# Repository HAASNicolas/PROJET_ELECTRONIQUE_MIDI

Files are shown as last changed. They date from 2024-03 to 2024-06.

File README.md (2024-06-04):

# PROJET_ELECTRONIQUE_MIDI
## Participants
* Lina Bachir
* Nicolas Haas
* Tanoh Koffi

## Code C
```C
int main (void)
{
  printf(C);
}
```

## Commandes github
Sous window: Dans le répertoire faire clique droit 'ouvrir un git bach', puis aller dans le bon dossier (si c'est pas déjà le cas):

Sous linux: Ouvrir un terminal, puis aller dans le bon dossier. Par exemple :
```
cd Documents/git_1A/PROJET_ELECTRONIQUE_MIDI/
```

Pour créer un nouveau répertoire git:
```
git config --global user.name "Pseudo git ou Nom Prénom"
git config --global user.email "Votre e-mail"
```
Testez
```
git clone adresse_du_git
```
Si git clone marche: Vous avez fini !
Sinon si git clone ne marche pas:
```
ssh-keygen
```
Faites Entrer plusieurs fois, puis copier l'adresse /c/....pub (example: /c/Users/user_name/.ssh/id_ed25519.pub)
```
cat adresse_pub_copié_ci_dessus
```
Copier ssh key, puis Ajouter ssh key sur github.com -> setting -> sshkey
```
git clone adresse_du_git
```

Pour récupérer les modifications distantes :
```
git pull
```

Pour pousser des modifications locales
```
git add .
git commit -m "Message à remplacer"
git push
```
# Rapport projet 
## Introduction

Notre projet consiste en la création d’un contrôleur MIDI, un dispositif électronique conçu pour interagir avec divers instruments et logiciels musicaux. Le contrôleur comporte une variété de boutons, de potentiomètres et de curseurs, offrant un contrôle précis et intuitif de nombreux aspects de la production musicale, tels que le volume, les effets, et la modulation.

La conception du contrôleur inclut l’intégration de plusieurs capteurs pour détecter les actions de l’utilisateur, qui sont ensuite traduites en signaux MIDI. Ces signaux sont transmis à un ordinateur ou un autre appareil musical via une interface MIDI, permettant un contrôle en temps réel de la musique.

Le développement de ce contrôleur MIDI inclut la mise en œuvre d’une carte électronique centrale, qui gère les signaux provenant des différents capteurs, ainsi qu’une interface de sortie pour la communication avec les appareils externes.

## objectif

L'objectif de notre projet est de concevoir un contrôleur MIDI fonctionnel et intuitif, permettant aux musiciens et aux producteurs de gérer et de manipuler leurs compositions musicales de manière fluide. 
Nous cherchons à créer un dispositif qui permette un contrôle précis et efficace des éléments clés de la production musicale, tels que le volume, les effets, et la modulation.

* Implémentation du MIDI classique

  Nous voulons une compatibilité universelle avec beaucoup d'instruments et de logiciels musicaux en adoptant le protocole MIDI standard. Notre contrôleur sera conçu pour envoyer et recevoir des messages MIDI de façon fiable, facilitant ainsi son intégration dans diverses configurations musicales.

* Support du MIDI USB via USB-C

  Notre objectif est d'incorporer une interface MIDI moderne utilisant un port USB-C, permettant une connexion simple et efficace avec des ordinateurs et autres appareils prenant en charge l'USB. Cela englobera la transmission de données MIDI ainsi que l'alimentation du contrôleur.

* Autonomie sur batterie rechargeable

  Nous planifions de développer un contrôleur fonctionnant sur une batterie rechargeable pour maximiser la portabilité et la flexibilité d'utilisation. La batterie sera rechargeable via USB-C, offrant ainsi aux utilisateurs la possibilité de jouer sans être dépendant d'une source d'alimentation fixe.

* Inspirations et benchmarking

  Nous nous baserons sur des modèles de référence tels que l'Intech Studio PBF4, le Faderfox MX12 pour l'ergonomie et l'AKAI MIDIMIX pour sa disposition efficace. Ces produits nous serviront de guide dans le développement de notre contrôleur.

* Cahier des charges:
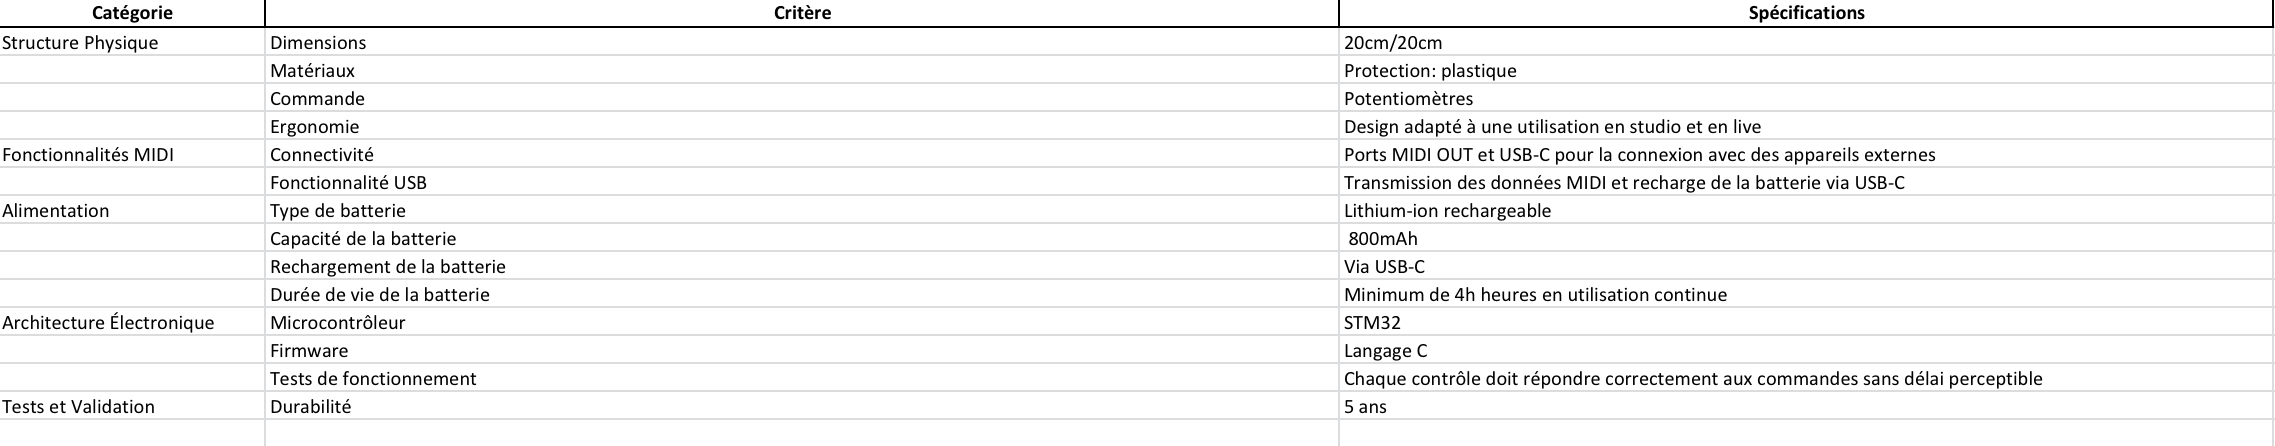
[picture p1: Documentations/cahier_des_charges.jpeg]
cahier des charges


* Planning des séances
planning

* Schéma global du projet

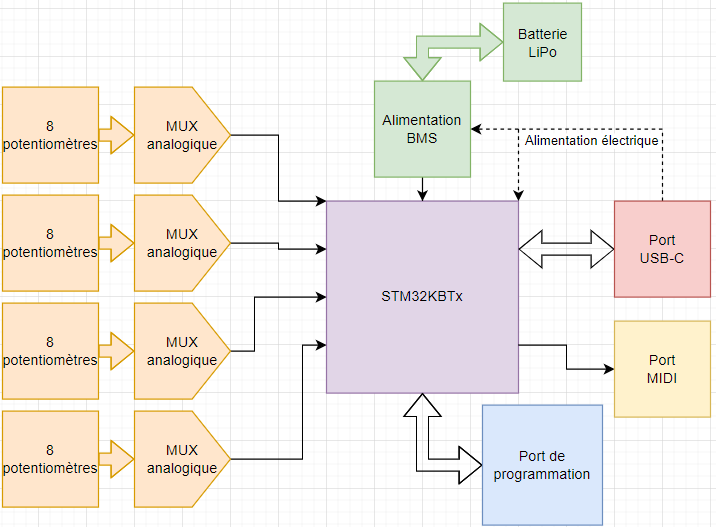
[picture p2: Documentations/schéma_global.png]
Schéma global du projet
  

## PCB 

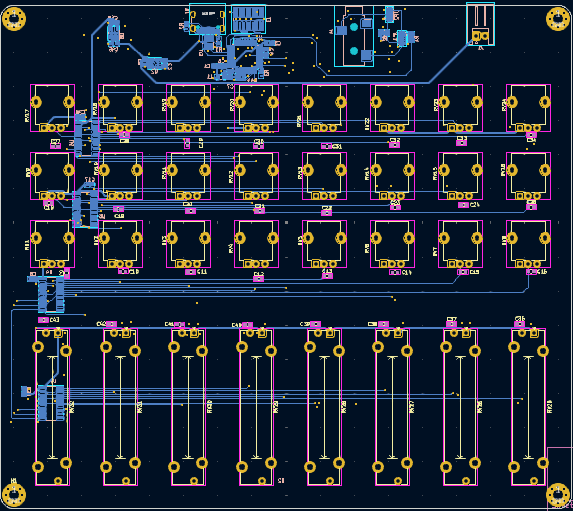
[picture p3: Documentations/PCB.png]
PCB


Dans cette partie de ce rapport, nous donnerons un aperçu complet de l'architecture et des composants du PCB de ce contrôleur MIDI.
On cherchera donc ici à comprendre le rôle des composants sur ce PCB et leur disposition.
Concernant le Microcontrôleur, ici le STM 32 KBTX, il est le centre du contrôleur MIDI. Son but ici est de gérer les entrées venues des boutons et potentiomètres, de traiter ces informations et d’envoyer les messages MIDI appropriés via les interfaces MIDI ou USB.

Quant aux Régulateurs de tension, ils assurent une tension stable pour alimenter les différents composants du circuit, par exemple, fournir 5V pour le microcontrôleur et 3.3V pour certains capteurs ou circuits.

On a aussi utilisé des Condensateurs pour filtrer les signaux, déparasiter les lignes d'alimentation et stabiliser les tensions. Ils sont essentiels pour réduire le bruit électronique et maintenir la stabilité des signaux. Ils sont dispersés autour du microcontrôleur et près des régulateurs de tension, souvent à proximité des broches d'alimentation pour optimiser leur efficacité. De plus, avec les Résistances, on parviendra à Limiter le courant, ajuster les niveaux de tension et effectuer des fonctions pull-up/pull-down sur les lignes de signal, elles sont quant à elles Connectées en série avec les boutons et situées près du microcontrôleur pour les pull-ups/pull-downs.

Le Connecteur MIDI utilisé ici va servir d’interface afin de connecter le contrôleur MIDI à d'autres dispositifs MIDI. Ce connecteur permet donc la communication des données MIDI. Un autre type de connecteur utilisé est le Connecteur USB qui va Permettre la connexion du contrôleur à un ordinateur pour la transmission de données MIDI et l'alimentation.

Les Traces, Les lignes rouges et bleues sur le schéma représentent les connexions électriques entre les composants. Les rouges sont sur la couche supérieure du PCB, et les bleues sur la couche inférieure. Elles sont connectées entre les différentes couches du PCB à l’aide des Vias, qui assurent ainsi une interconnexion entre les couches du PCB. Les potentiomètres, eux, capturent les entrées de l'utilisateur. Chaque potentiomètre envoie en effet un signal spécifique au microcontrôleur.

En outre, Le microcontrôleur central gère les entrées venues des boutons et les interfaces MIDI/USB. Les régulateurs de tension, condensateurs et résistances assurent la stabilité du circuit et les connecteurs MIDI et USB permettent la communication avec d'autres dispositifs MIDI et des ordinateurs.
En résumé, lorsqu'on modifie la position d’un potentiomètre du contrôleur MIDI, le microcontrôleur détecte ce changement et identifie le potentiomètre en question. Il génère ensuite un message MIDI avec les informations appropriées (comme la note et la vélocité). Ce message est transmis soit via le connecteur MIDI DIN à d'autres appareils MIDI, soit via USB à un ordinateur.

## Résultats
Nous avons réussi à faire fonctionner la carte, et a lui faire envoyer, via l'USART, des trames MIDI correspondants aux valeurs des potentiomètres.

Voici les valeurs que renvoient un des potentiomètres linéaire et un des potentiomètres rond. C'est valeurs doivent être comprise entre 0 et 127, car en MIDI on la code sur 7 bits.
Sel est le numéro transmis aux 4 MUX analogiques.
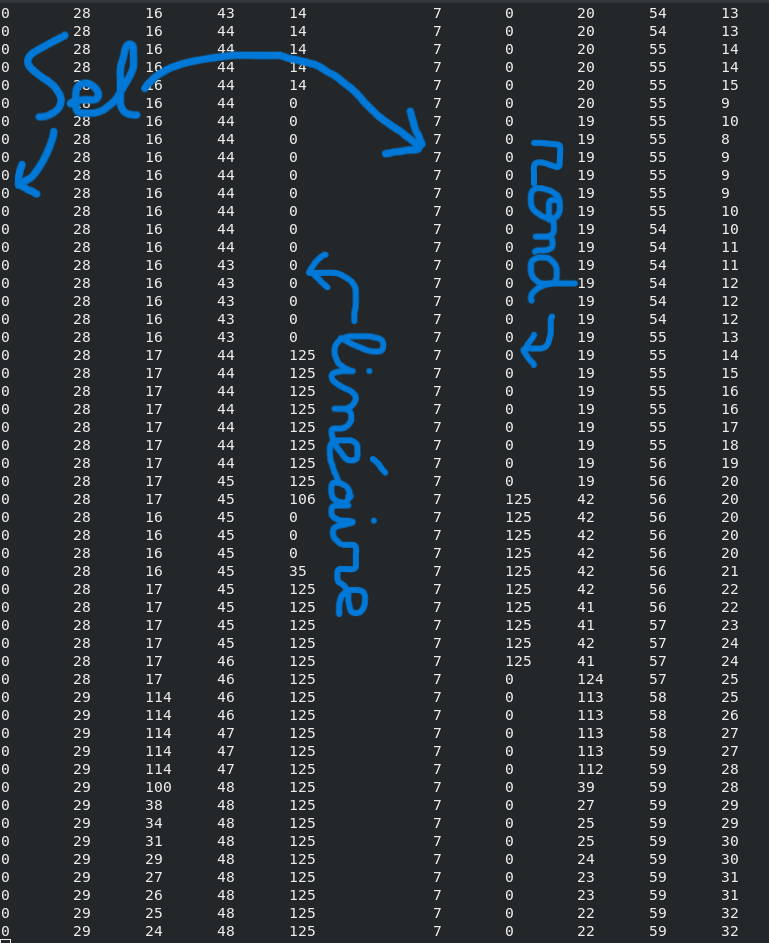
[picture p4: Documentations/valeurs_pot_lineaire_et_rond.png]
Valeurs des potentiomètres


La carte regarde en boucle la valeur des potentiomètres. Si la valeur change, alors une trame MIDI est envoyée.

Comme l'ADC fait 4 conversions à la fois, nous pouvons voir 4 trames MIDI qui ce suivent:
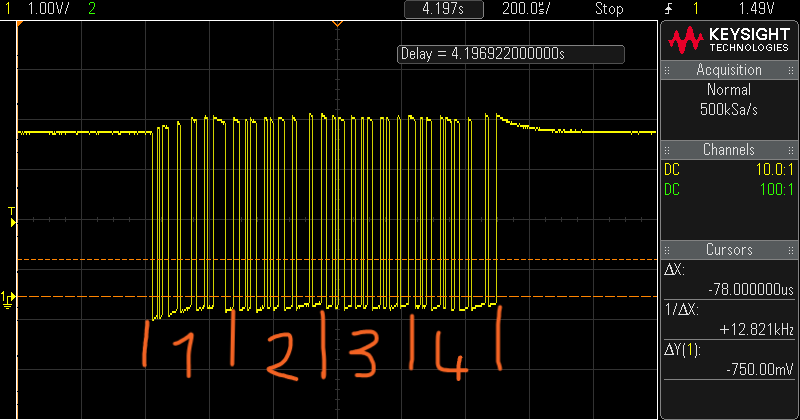
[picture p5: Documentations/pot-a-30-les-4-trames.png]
4 trames MIDI


Chaque trame comporte 3 octets, ayant chacun leur bit de start à 0.
* Le 1er octet et l'identifiant ici 0x1A
* Le 2e est le numéro du potentiomètre ici 24
* Le 3e et dernier est la valeur du potentiomètre (ici 30) codée sur 7 bits (donc le MSB qui se situe à droite est toujours à 0)

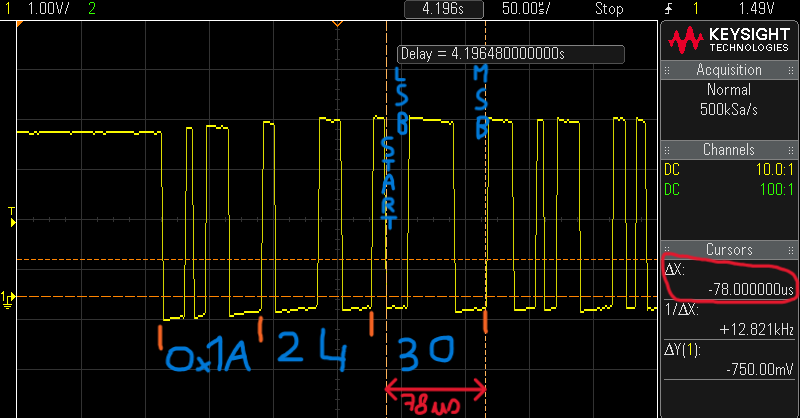
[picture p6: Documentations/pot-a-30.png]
Trame MIDI d'un potentiomètre de valeur 30


On remarque que les curseurs sont espacés de 9 bits et d'une durée de 78us. Ce qui est en accord avec notre programme que nous avons configuré pour émettre à une vitesse de 115200 bauds.

## Code

Voici le diagramme de notre code:

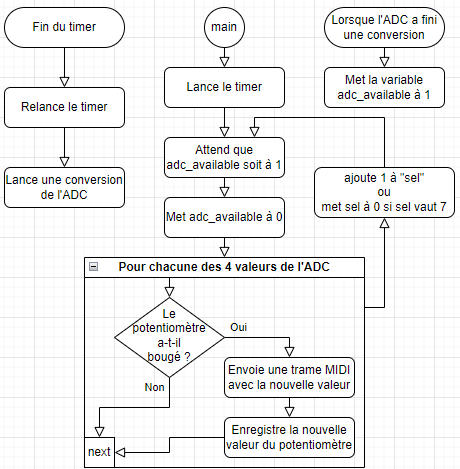
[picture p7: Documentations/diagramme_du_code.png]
Diagramme du code


## Les difficultés rencontrées

* Lors de schéma afain d'avoir les bonnes valeurs des résistances et condensateurs.
* Le routage nous a aussi appris qu'il faut mettre des composants de protections, ainsi que le BMS pour la recharge de la batterie.
* Dans le routage, qui nous ont permis d'apprendre les bonnes pratiques.
* L'USART du STM32 ne voulait pas fonctionner en Half-Duplex, on a donc dû le mettre en Asynchronous. Nous avons donc la broche TX qui ne sert à rien.
* Pour le soudage de composants CMS, car il faut être précis.

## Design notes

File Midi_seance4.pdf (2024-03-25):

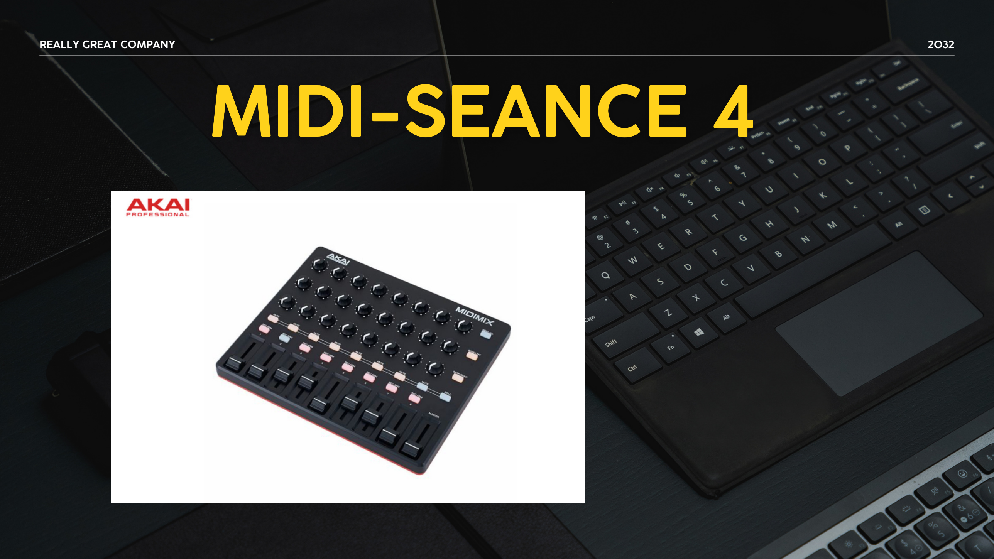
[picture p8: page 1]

REALLY GREAT COMPANY | 2032

3

1.

# 2. DEBUT ROUTAGE

# FIN SHEMA KICAD

# SCHEMA KICAD

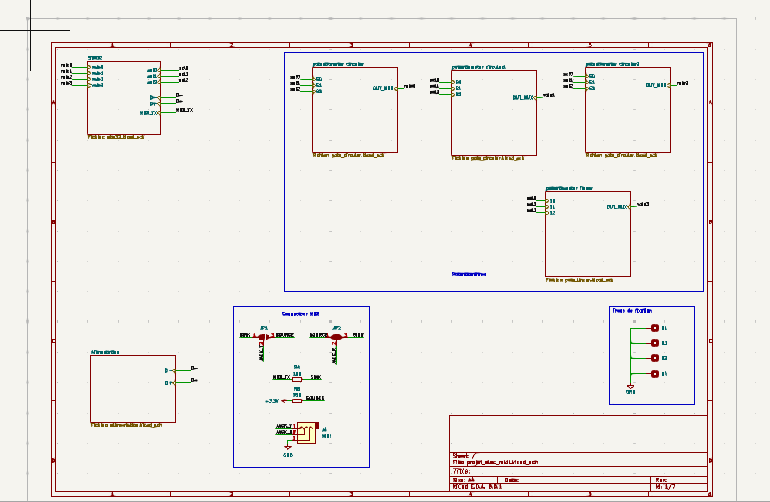
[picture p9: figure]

# KICAD

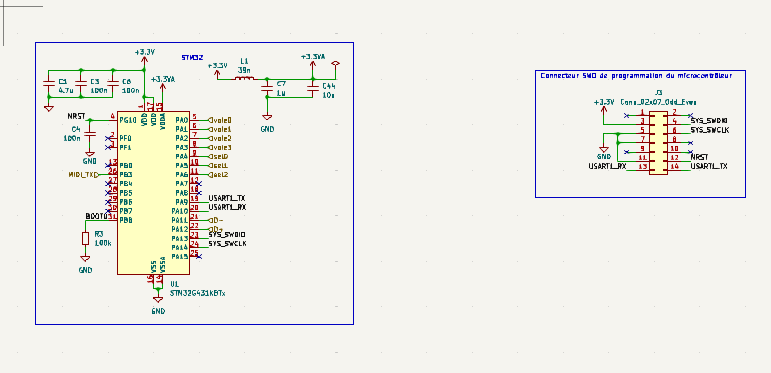
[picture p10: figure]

# KICAD

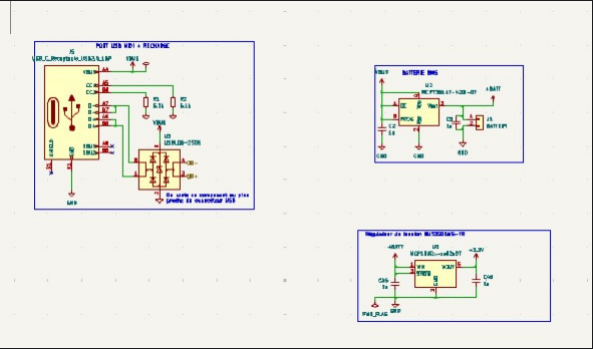
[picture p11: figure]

# KICAD

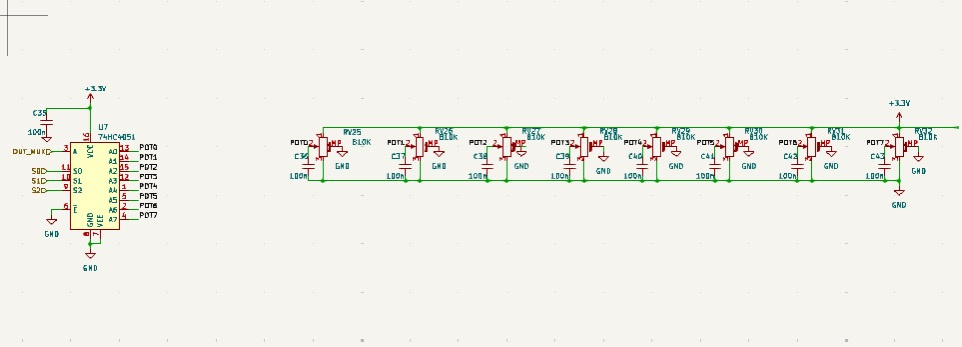
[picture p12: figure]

# ROUTAGE

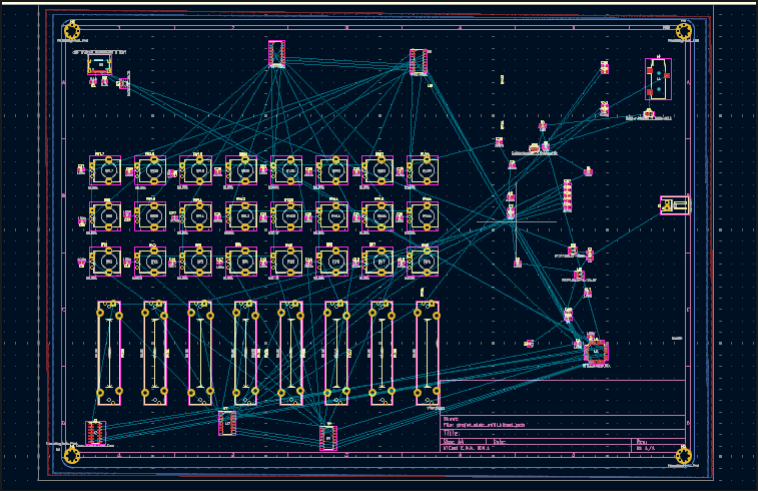
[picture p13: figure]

# MERCI !

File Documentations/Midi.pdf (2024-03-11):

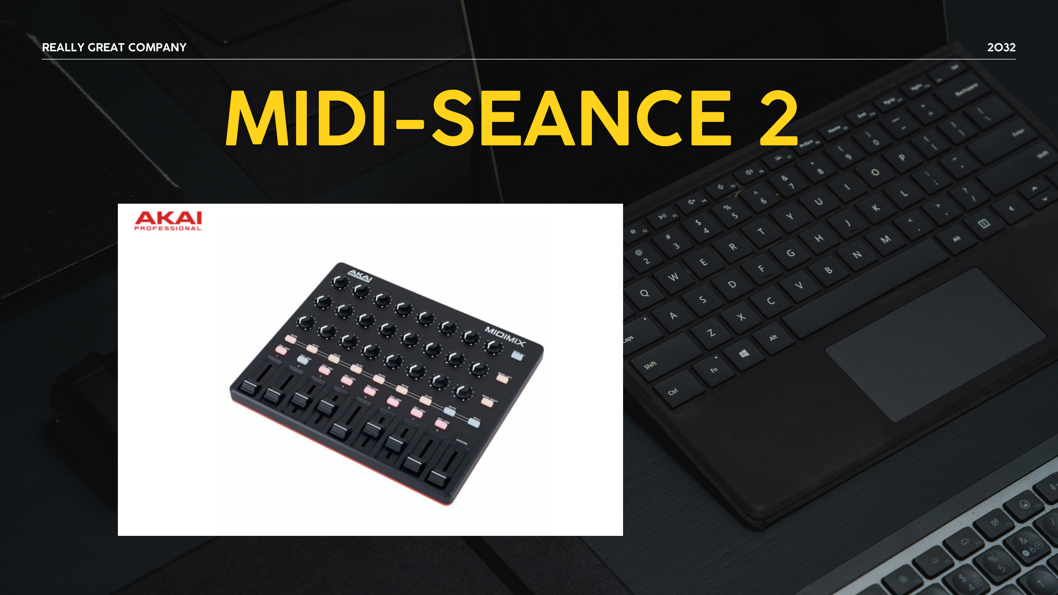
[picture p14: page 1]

REALLY GREAT COMPANY | 2032

3

1.

# 2. DEBUT KICAD

# CHOIX DES COMPOSANTS

1.

# 2. DEBUT KICAD

# CHOIX DES COMPOSANTS

# CHOIX DES COMPOSANTS

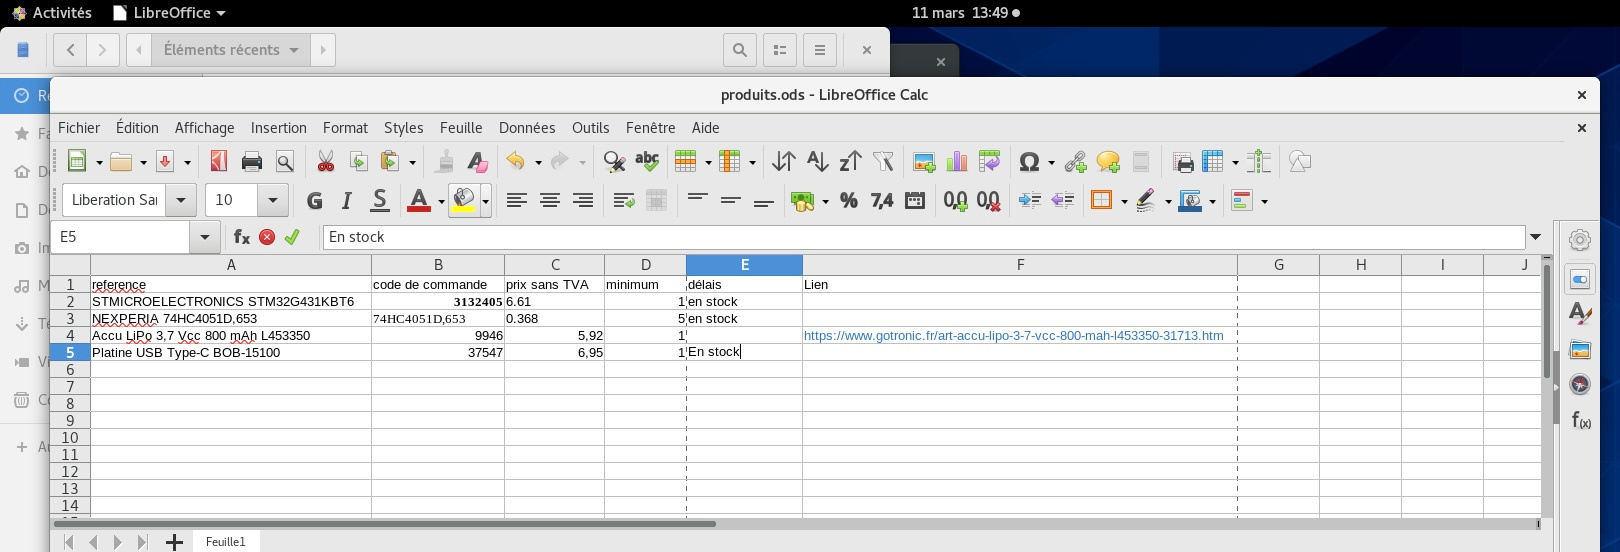
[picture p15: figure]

# DEBUT KICAD

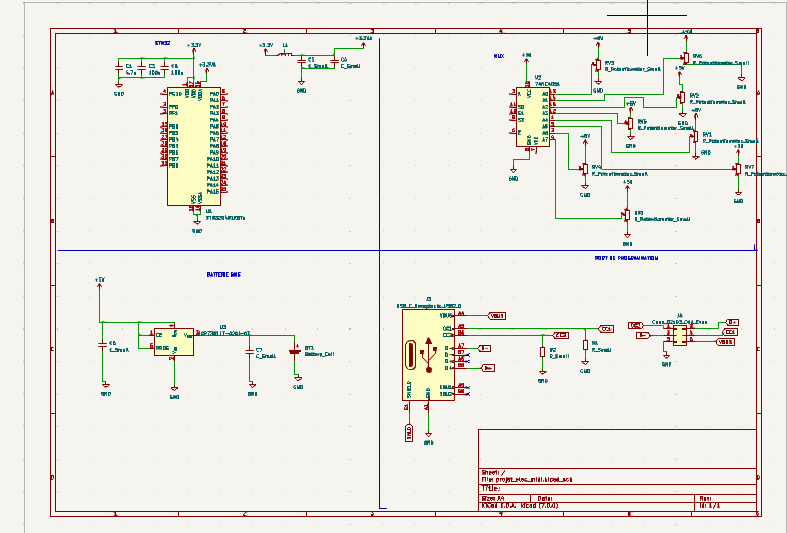
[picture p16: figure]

# MERCI !

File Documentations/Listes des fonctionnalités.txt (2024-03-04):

-recevoir en entrée plusieurs sons et émettre en sortie un seul son
- Contrôler le volume du son, la panoramique, le gain 
-

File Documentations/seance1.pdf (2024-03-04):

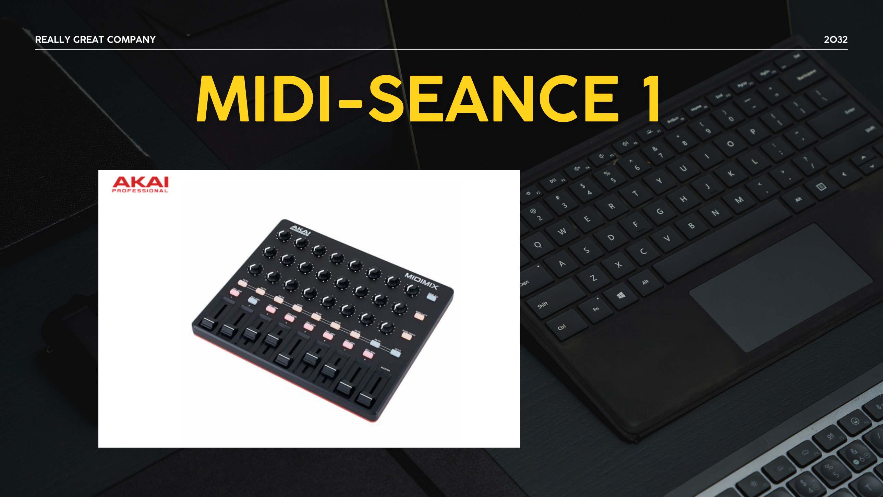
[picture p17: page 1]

REALLY GREAT COMPANY | 2032

REALLY GREAT COMPANY | 2032

3

1.

# 2.SCHEMA ARCHITECTURAL

# LISTE DES COMPOSANTS

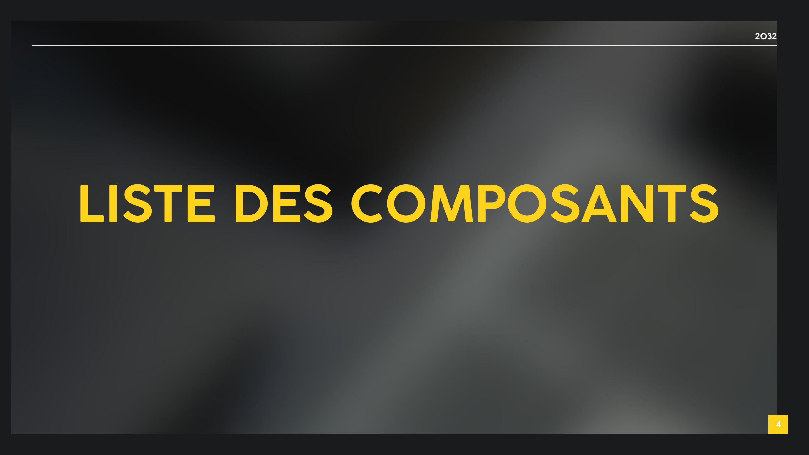
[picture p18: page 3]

4

2032

# LISTE DES COMPOSANTS

5

# 32 POTENTIOMETRE MULTIPLEXEUR ANALOGIQUE BATTERIE PORT DE PROGRAMMATION

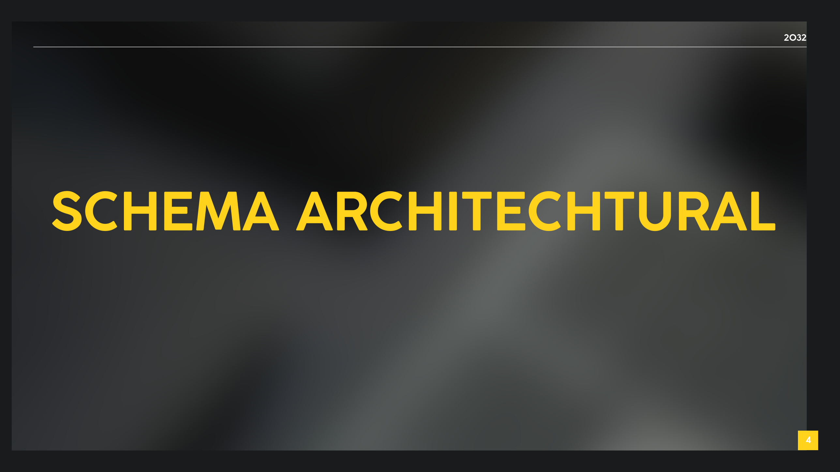
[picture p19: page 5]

4

# SCHEMA ARCHITECHTURAL

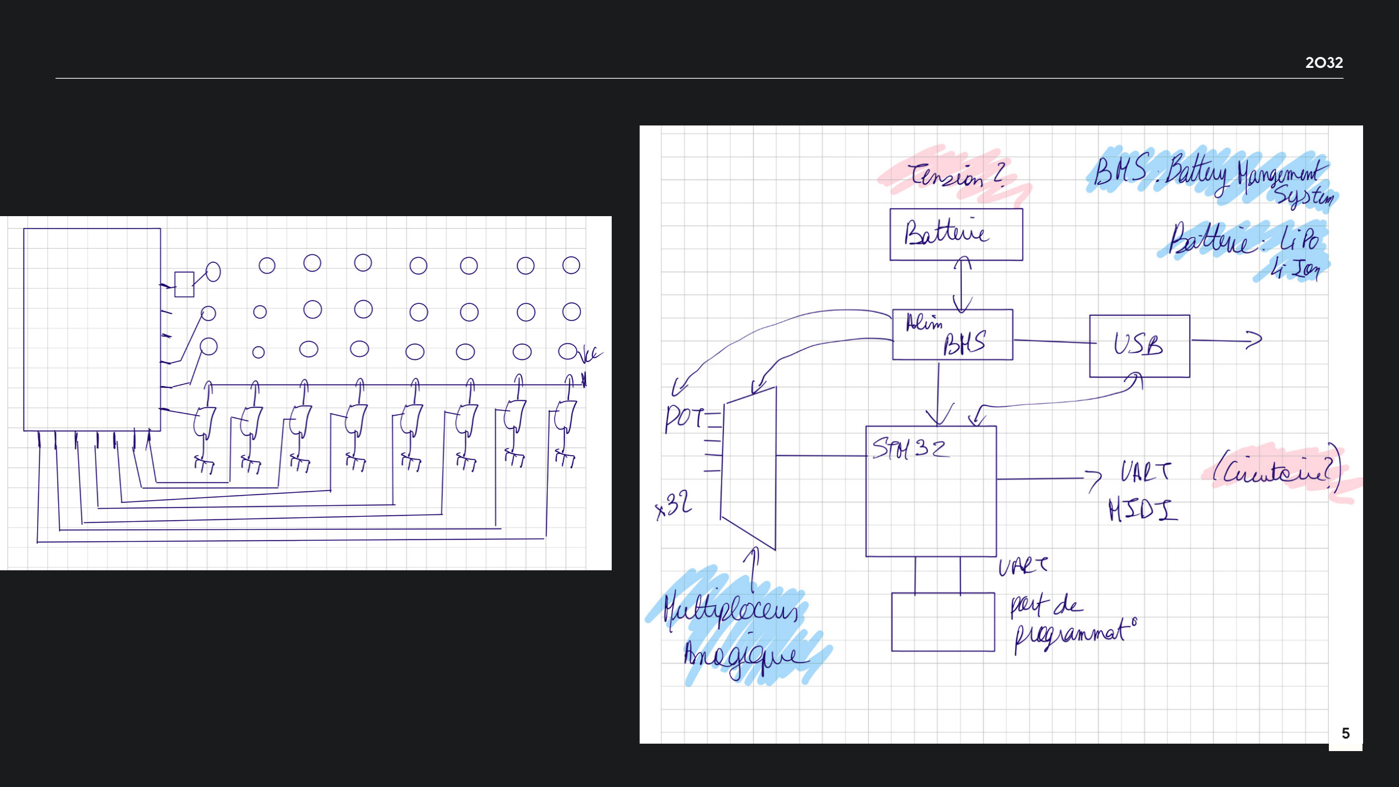
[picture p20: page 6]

5

# MERCI !

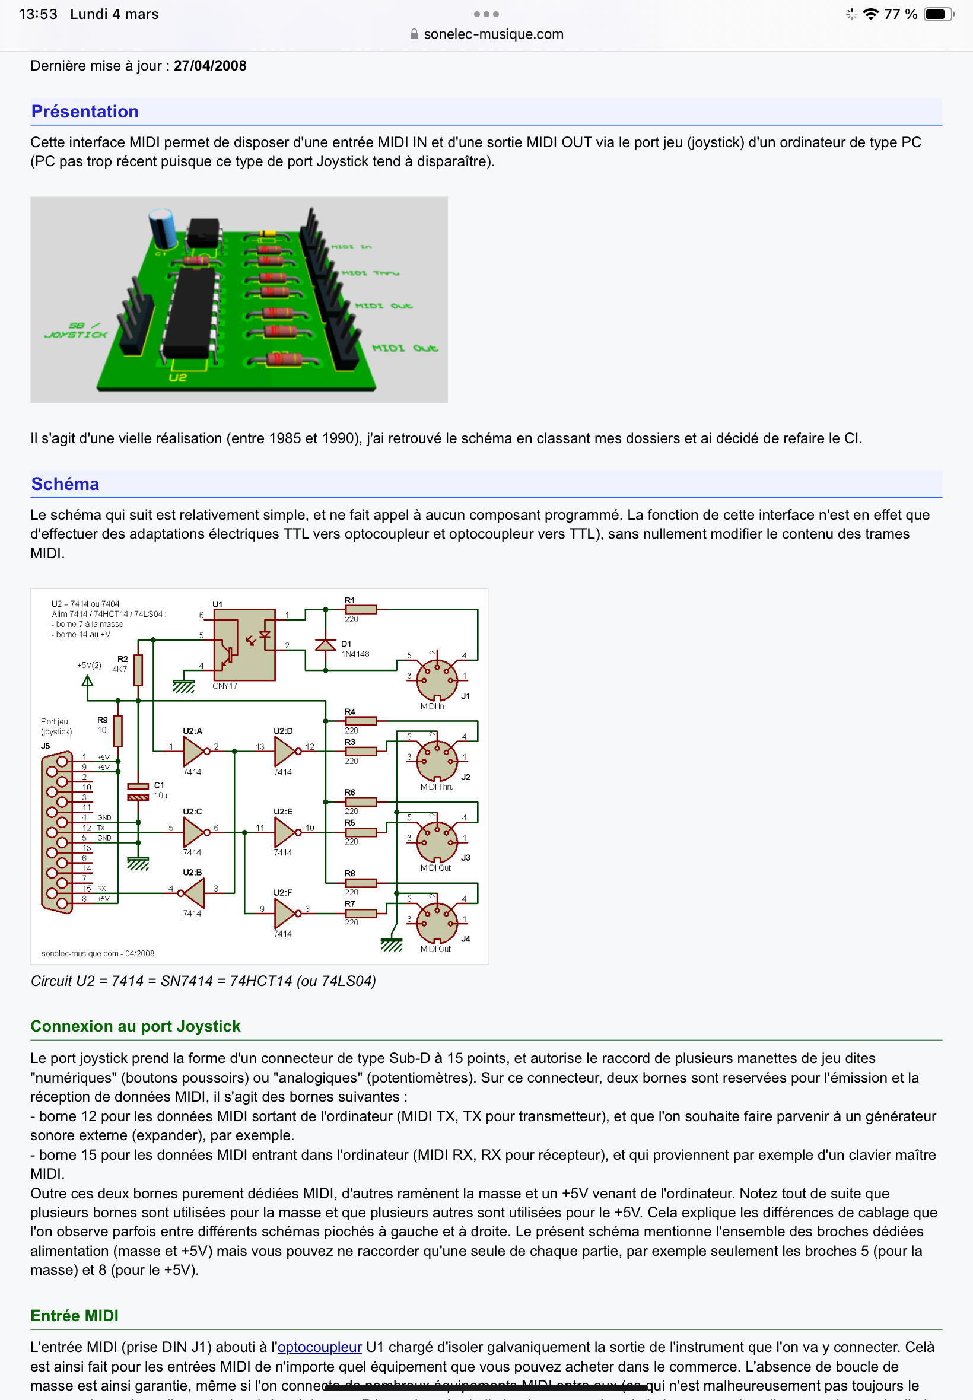
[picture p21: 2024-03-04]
Documentations/son-elec.png

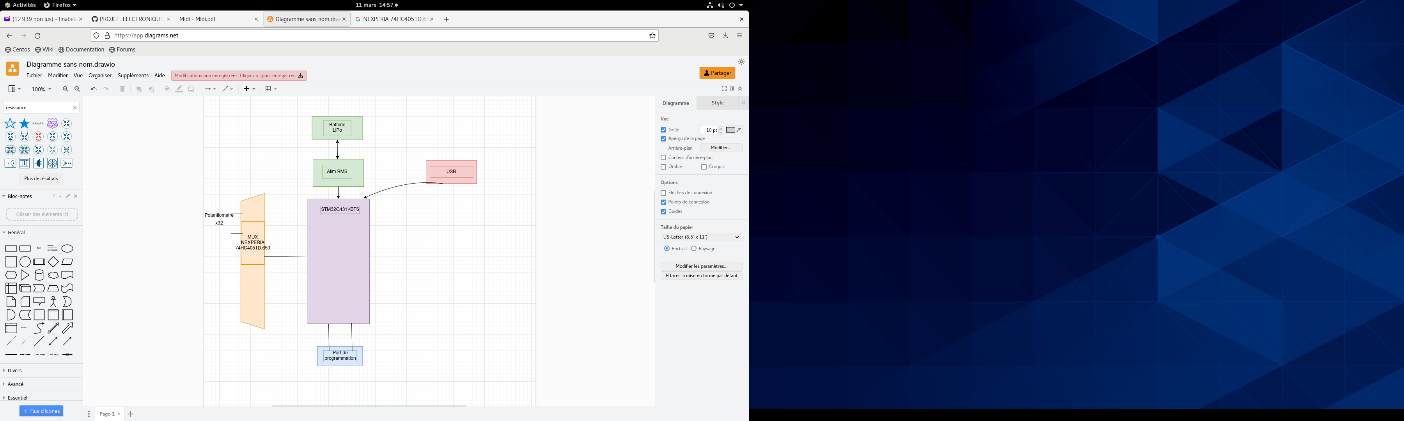
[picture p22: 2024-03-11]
Documentations/schema.draw.io.png

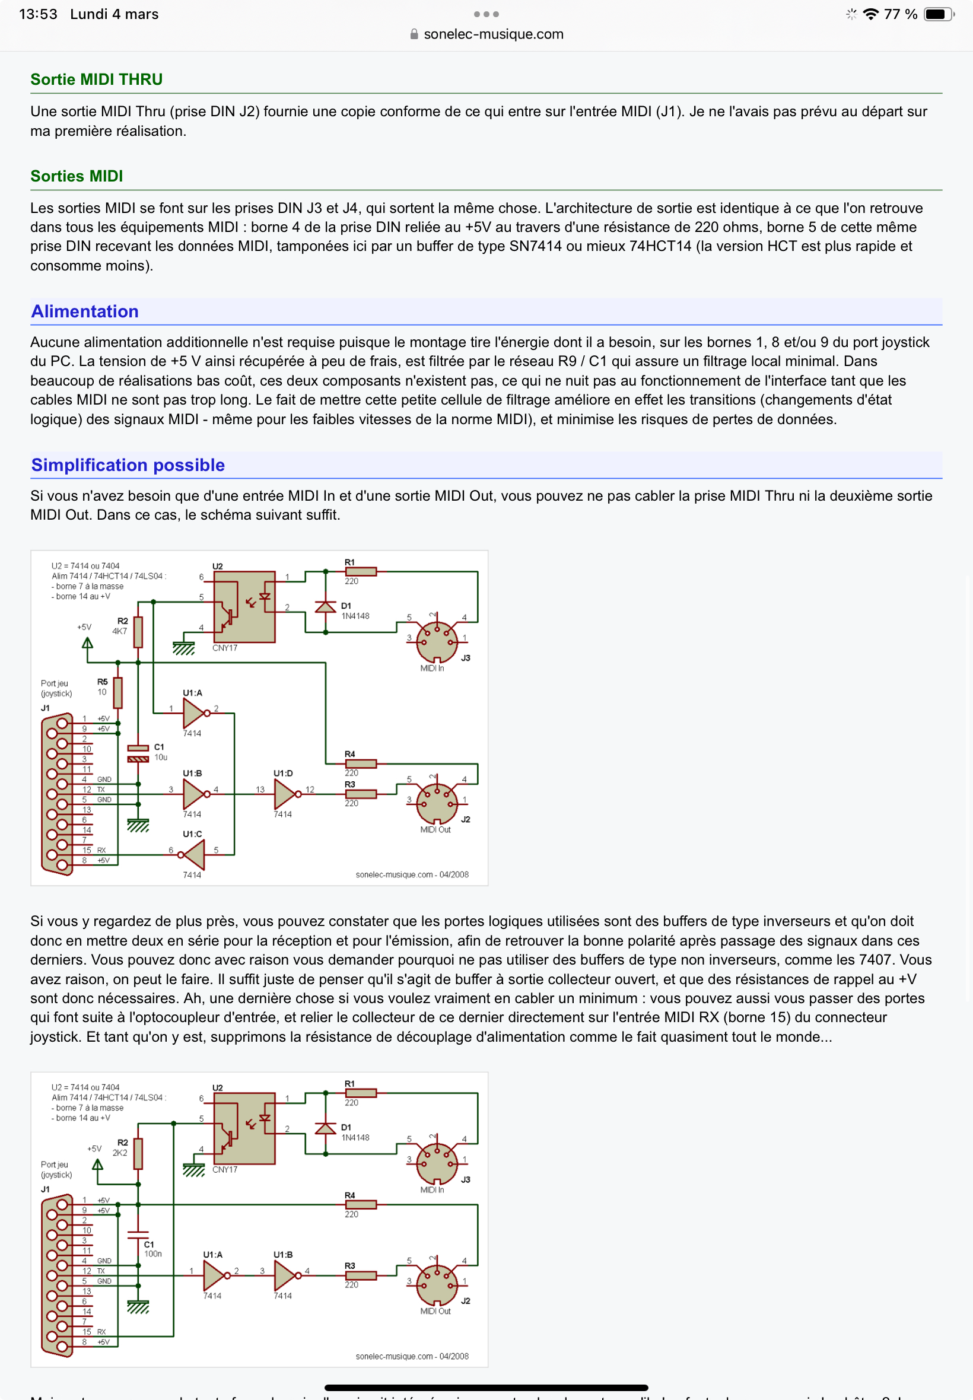
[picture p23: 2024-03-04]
Documentations/Electronique - Realisations - Interface MIDI 001.png

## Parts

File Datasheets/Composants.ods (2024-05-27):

Reference | Value | Footprint | Qty | On A
C1 | 4.7u | Capacitor_SMD:C_0603_1608Metric | 1
C2,C5,C7,C45,C46 | 1u | -- valeurs mixtées -- | 5
C3,C4,C6,C8,C9,C10,C11,C12,C13,C14,C15,C16,C17,C18,C19,C20,C21,C22,C23,C24,C25,C26,C27,C28,C29,C30,C31,C32,C33,C34,C35,C36,C37,C38,C39,C40,C41,C42,C43 | 100n | Capacitor_SMD:C_0603_1608Metric | 39
C44 | 10n | Capacitor_SMD:C_0603_1608Metric | 1
H1,H2,H3,H4 | MountingHole_Pad | MountingHole:MountingHole_3.2mm_M3_Pad_Via | 4
J1 | BATTERY | Connector_JST:JST_XH_S2B-XH-A_1x02_P2.50mm_Horizontal | 1
J3 | Conn_02x07_Odd_Even | Connector_PinHeader_1.27mm:PinHeader_2x07_P1.27mm_Vertical_SMD | 1
J4 | MIDI | Connector_Audio:Jack_3.5mm_CUI_SJ-3523-SMT_Horizontal | 1
J5 | USB_C_Receptacle_USB2.0_16P | Connector_USB:USB_C_Receptacle_GCT_USB4105-xx-A_16P_TopMnt_Horizontal | 1
JP1,JP2 | SolderJumper_3_Bridged12 | Jumper:SolderJumper-3_P1.3mm_Bridged12_RoundedPad1.0x1.5mm | 2
L1 | 39n | Inductor_SMD:L_0805_2012Metric | 1
R1,R2 | 5.1k | Resistor_SMD:R_0603_1608Metric | 2
R3 | 100k | Resistor_SMD:R_0603_1608Metric | 1
R4 | 10R | Resistor_SMD:R_0805_2012Metric | 1
R5 | 33R | Resistor_SMD:R_0805_2012Metric | 1
RV1,RV2,RV3,RV4,RV5,RV6,RV7,RV8,RV9,RV10,RV11,RV12,RV13,RV14,RV15,RV16,RV17,RV18,RV19,RV20,RV21,RV22,RV23,RV24 | B100k | Potentiometer_THT:Potentiometer_Alpha_RD901F-40-00D_Single_Vertical | 24
RV25,RV26,RV27,RV28,RV29,RV30,RV31,RV32 | B10K | Potentiometer_THT:Potentiometer_Bourns_PTA3043_Single_Slide | 8
U1 | STM32G431KBTx | Package_QFP:LQFP-32_7x7mm_P0.8mm | 1 | OUI
U2 | MCP73811T-420I-OT | Package_TO_SOT_SMD:SOT-23-5 | 1 | OUI
U3 | USBLC6-2SC6 | Package_TO_SOT_SMD:SOT-23-6 | 1
U4,U5,U6,U7 | 74HC4051 | Package_SO:SO-16_3.9x9.9mm_P1.27mm | 4 | OUI
U8 | MCP1802x-xx02xOT | Package_TO_SOT_SMD:SOT-23-5 | 1

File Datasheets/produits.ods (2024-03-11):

reference | code de commande | prix sans TVA | minimum | délais | Lien
STMICROELECTRONICS STM32G431KBT6 | x | x | x | x
MUX NEXPERIA 74HC4051D,653 | 74HC4051D,653 | 0.368 | 5 | en stock | Farnell
Accu LiPo 3,7 Vcc 800 mAh L453350 | 9946 | 5,92 | 1 |  | https://www.gotronic.fr/art-accu-lipo-3-7-vcc-800-mah-l453350-31713.htm
USBC | x | x | x | x
MCP73811T-420I/OT | 1439477 |  |  |  | Farnell
potentiometre
jack midi

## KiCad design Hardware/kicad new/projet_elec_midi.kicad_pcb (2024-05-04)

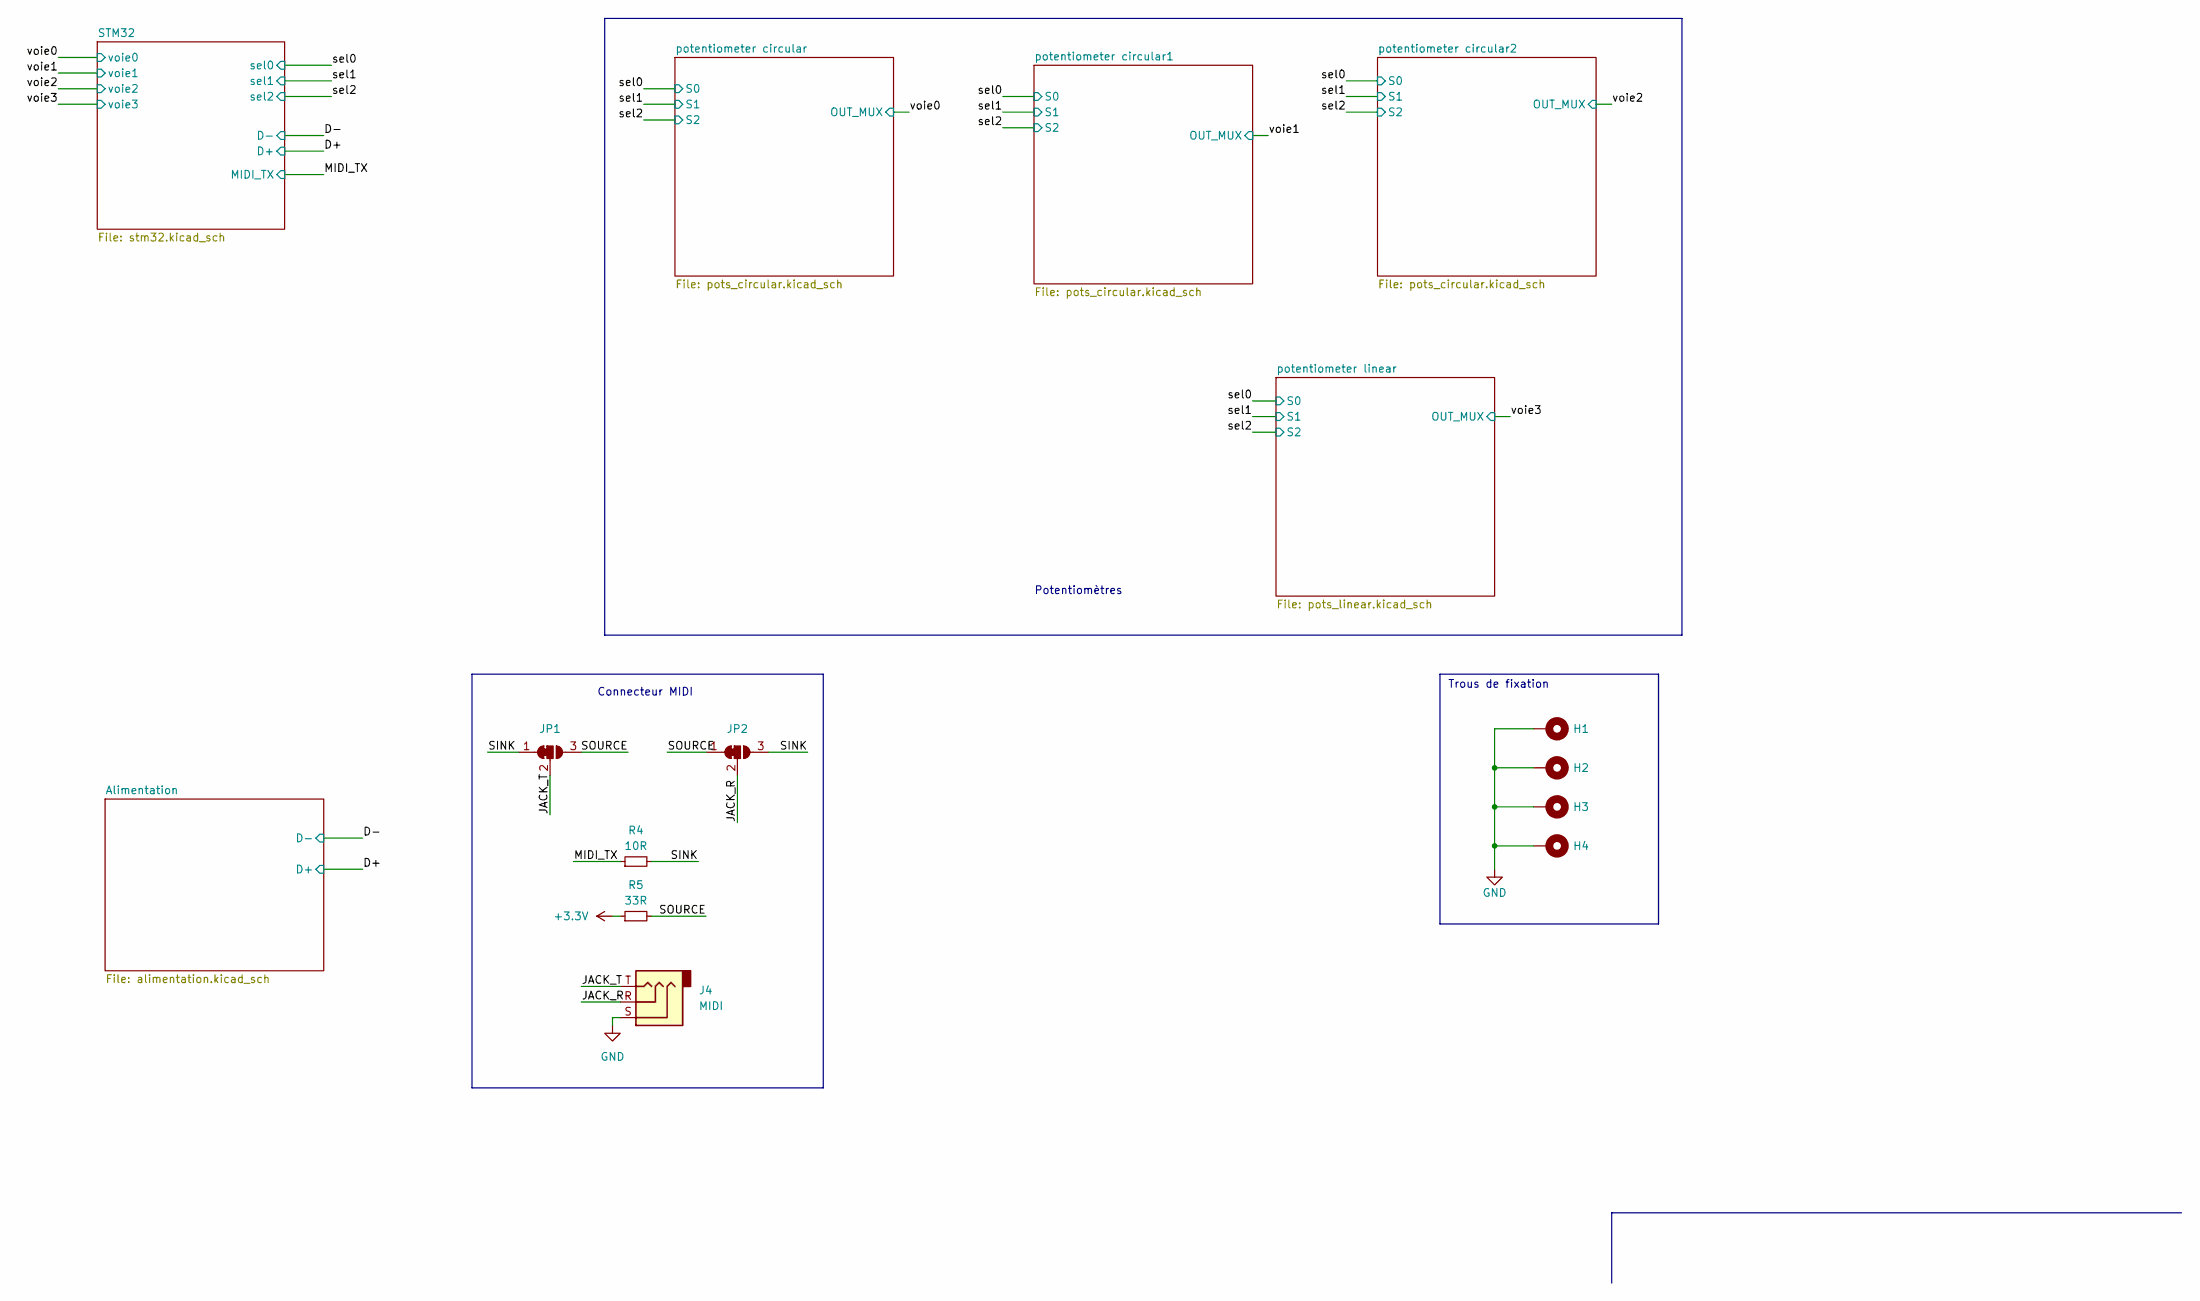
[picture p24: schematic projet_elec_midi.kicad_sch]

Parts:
H1, H2, H3, H4: MountingHole_Pad; MountingHole_3.2mm_M3_Pad_Via
J4: MIDI; Jack_3.5mm_CUI_SJ-3523-SMT_Horizontal
JP1, JP2: SolderJumper_3_Bridged12; SolderJumper-3_P1.3mm_Bridged12_RoundedPad1.0x1.5mm
R4: 10R; R_0805_2012Metric
R5: 33R; R_0805_2012Metric

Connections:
+3.3V: R5.1; also elsewhere on the board
/JACK_R: J4.R, JP2.2 (C)
/JACK_T: J4.T, JP1.2 (C)
/MIDI_TX: R4.1; also elsewhere on the board
/SINK: JP1.1 (A), JP2.3 (B), R4.2
/SOURCE: JP1.3 (B), JP2.1 (A), R5.2
GND: H1.1, H2.1, H3.1, H4.1, J4.S; also elsewhere on the board

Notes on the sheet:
Trous de fixation
Potentiomètres
Connecteur MIDI

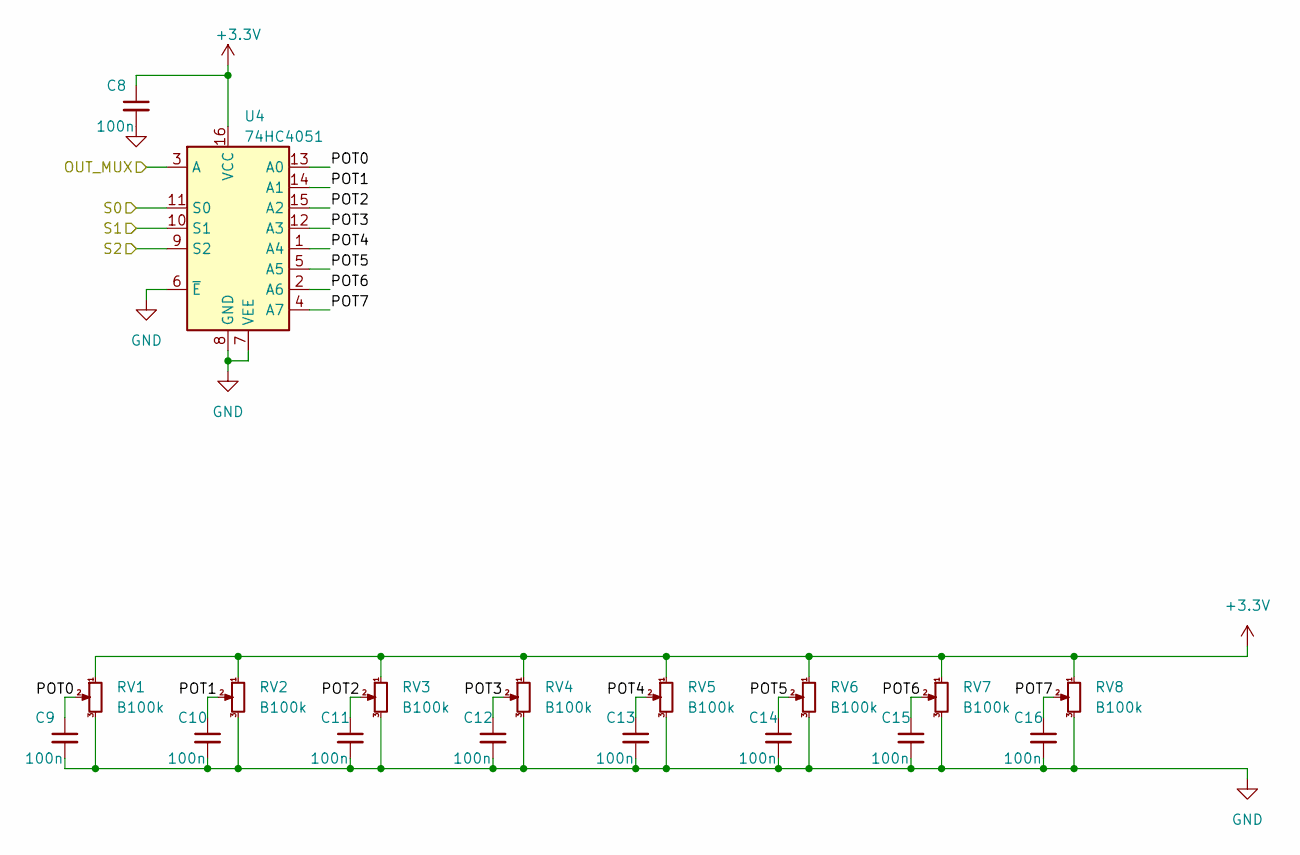
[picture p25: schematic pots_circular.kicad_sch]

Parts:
C8, C9, C10, C11, C12, C13, C14, C15, C16: 100n; C_0603_1608Metric
RV1, RV2, RV3, RV4, RV5, RV6, RV7, RV8: B100k; Potentiometer_Alpha_RD901F-40-00D_Single_Vertical
U4: 74HC4051; SO-16_3.9x9.9mm_P1.27mm

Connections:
+3.3V: C8.1, RV1.1, RV2.1, RV3.1, RV4.1, RV5.1, RV6.1, RV7.1, RV8.1, U4.16 (VCC); also elsewhere on the board
/potentiometer circular/POT0: C9.1, RV1.2, U4.13 (A0)
/potentiometer circular/POT1: C10.1, RV2.2, U4.14 (A1)
/potentiometer circular/POT2: C11.1, RV3.2, U4.15 (A2)
/potentiometer circular/POT3: C12.1, RV4.2, U4.12 (A3)
/potentiometer circular/POT4: C13.1, RV5.2, U4.1 (A4)
/potentiometer circular/POT5: C14.1, RV6.2, U4.5 (A5)
/potentiometer circular/POT6: C15.1, RV7.2, U4.2 (A6)
/potentiometer circular/POT7: C16.1, RV8.2, U4.4 (A7)
/sel0: U4.11 (S0); also elsewhere on the board
/sel1: U4.10 (S1); also elsewhere on the board
/sel2: U4.9 (S2); also elsewhere on the board
/voie0: U4.3 (A); also elsewhere on the board
GND: C8.2, C9.2, C10.2, C11.2, C12.2, C13.2, C14.2, C15.2, C16.2, RV1.3, RV2.3, RV3.3, RV4.3, RV5.3, RV6.3, RV7.3, RV8.3, U4.6 (~E), U4.7 (VEE), U4.8 (GND); also elsewhere on the board

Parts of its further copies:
C17, C18, C19, C20, C21, C22, C23, C24, C25, C26, C27, C28, C29, C30, C31, C32, C33, C34: 100n; C_0603_1608Metric
RV9, RV10, RV11, RV12, RV13, RV14, RV15, RV16, RV17, RV18, RV19, RV20, RV21, RV22, RV23, RV24: B100k; Potentiometer_Alpha_RD901F-40-00D_Single_Vertical
U5, U6: 74HC4051; SO-16_3.9x9.9mm_P1.27mm

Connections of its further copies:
+3.3V: C17.1, C26.1, RV9.1, RV10.1, RV11.1, RV12.1, RV13.1, RV14.1, RV15.1, RV16.1, RV17.1, RV18.1, RV19.1, RV20.1, RV21.1, RV22.1, RV23.1, RV24.1, U5.16 (VCC), U6.16 (VCC); also elsewhere on the board
/potentiometer circular1/POT0: C18.1, RV9.2, U5.13 (A0)
/potentiometer circular1/POT1: C19.1, RV10.2, U5.14 (A1)
/potentiometer circular1/POT2: C20.1, RV11.2, U5.15 (A2)
/potentiometer circular1/POT3: C21.1, RV12.2, U5.12 (A3)
/potentiometer circular1/POT4: C22.1, RV13.2, U5.1 (A4)
/potentiometer circular1/POT5: C23.1, RV14.2, U5.5 (A5)
/potentiometer circular1/POT6: C24.1, RV15.2, U5.2 (A6)
/potentiometer circular1/POT7: C25.1, RV16.2, U5.4 (A7)
/potentiometer circular2/POT0: C27.1, RV17.2, U6.13 (A0)
/potentiometer circular2/POT1: C28.1, RV18.2, U6.14 (A1)
/potentiometer circular2/POT2: C29.1, RV19.2, U6.15 (A2)
/potentiometer circular2/POT3: C30.1, RV20.2, U6.12 (A3)
/potentiometer circular2/POT4: C31.1, RV21.2, U6.1 (A4)
/potentiometer circular2/POT5: C32.1, RV22.2, U6.5 (A5)
/potentiometer circular2/POT6: C33.1, RV23.2, U6.2 (A6)
/potentiometer circular2/POT7: C34.1, RV24.2, U6.4 (A7)
/sel0: U5.11 (S0), U6.11 (S0); also elsewhere on the board
/sel1: U5.10 (S1), U6.10 (S1); also elsewhere on the board
/sel2: U5.9 (S2), U6.9 (S2); also elsewhere on the board
/voie1: U5.3 (A); also elsewhere on the board
/voie2: U6.3 (A); also elsewhere on the board
GND: C17.2, C18.2, C19.2, C20.2, C21.2, C22.2, C23.2, C24.2, C25.2, C26.2, C27.2, C28.2, C29.2, C30.2, C31.2, C32.2, C33.2, C34.2, RV9.3, RV10.3, RV11.3, RV12.3, RV13.3, RV14.3, RV15.3, RV16.3, RV17.3, RV18.3, RV19.3, RV20.3, RV21.3, RV22.3, RV23.3, RV24.3, U5.6 (~E), U5.7 (VEE), U5.8 (GND), U6.6 (~E), U6.7 (VEE), U6.8 (GND); also elsewhere on the board

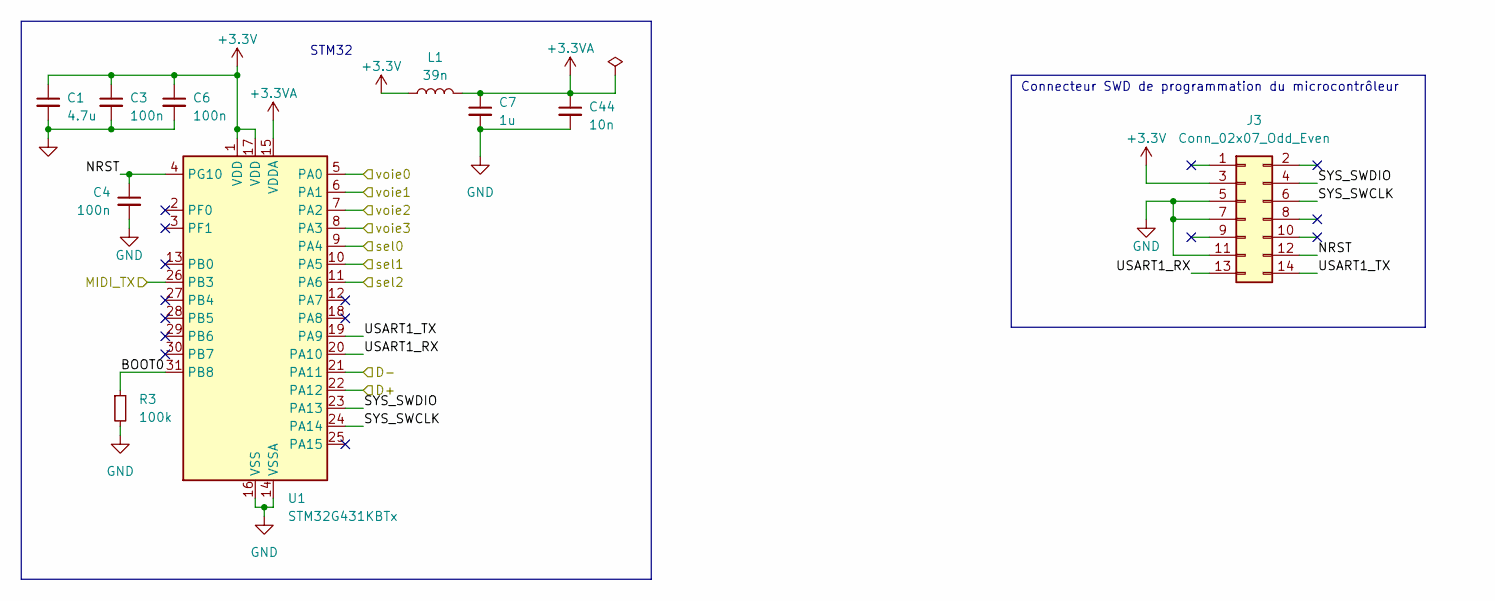
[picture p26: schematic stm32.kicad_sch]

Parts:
C1: 4.7u; C_0603_1608Metric
C3, C4, C6: 100n; C_0603_1608Metric
C7: 1u; C_0603_1608Metric
C44: 10n; C_0603_1608Metric
J3: Conn_02x07_Odd_Even; PinHeader_2x07_P1.27mm_Vertical_SMD
L1: 39n; L_0805_2012Metric
R3: 100k; R_0603_1608Metric
U1: STM32G431KBTx; LQFP-32_7x7mm_P0.8mm

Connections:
+3.3V: C1.1, C3.1, C6.1, J3.3, L1.1, U1.1 (VDD), U1.17 (VDD); also elsewhere on the board
+3.3VA: C7.1, C44.1, L1.2, U1.15 (VDDA)
/D+: U1.22 (PA12); also elsewhere on the board
/D-: U1.21 (PA11); also elsewhere on the board
/MIDI_TX: U1.26 (PB3); also elsewhere on the board
/STM32/BOOT0: R3.1, U1.31 (PB8)
/STM32/NRST: C4.1, J3.12, U1.4 (PG10)
/STM32/SYS_SWCLK: J3.6, U1.24 (PA14)
/STM32/SYS_SWDIO: J3.4, U1.23 (PA13)
/STM32/USART1_RX: J3.13, U1.20 (PA10)
/STM32/USART1_TX: J3.14, U1.19 (PA9)
/sel0: U1.9 (PA4); also elsewhere on the board
/sel1: U1.10 (PA5); also elsewhere on the board
/sel2: U1.11 (PA6); also elsewhere on the board
/voie0: U1.5 (PA0); also elsewhere on the board
/voie1: U1.6 (PA1); also elsewhere on the board
/voie2: U1.7 (PA2); also elsewhere on the board
/voie3: U1.8 (PA3); also elsewhere on the board
GND: C1.2, C3.2, C4.2, C6.2, C7.2, C44.2, J3.5, J3.7, J3.11, R3.2, U1.14 (VSSA), U1.16 (VSS), U1.32 (VSS); also elsewhere on the board

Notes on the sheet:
STM32
Connecteur SWD de programmation du microcontrôleur

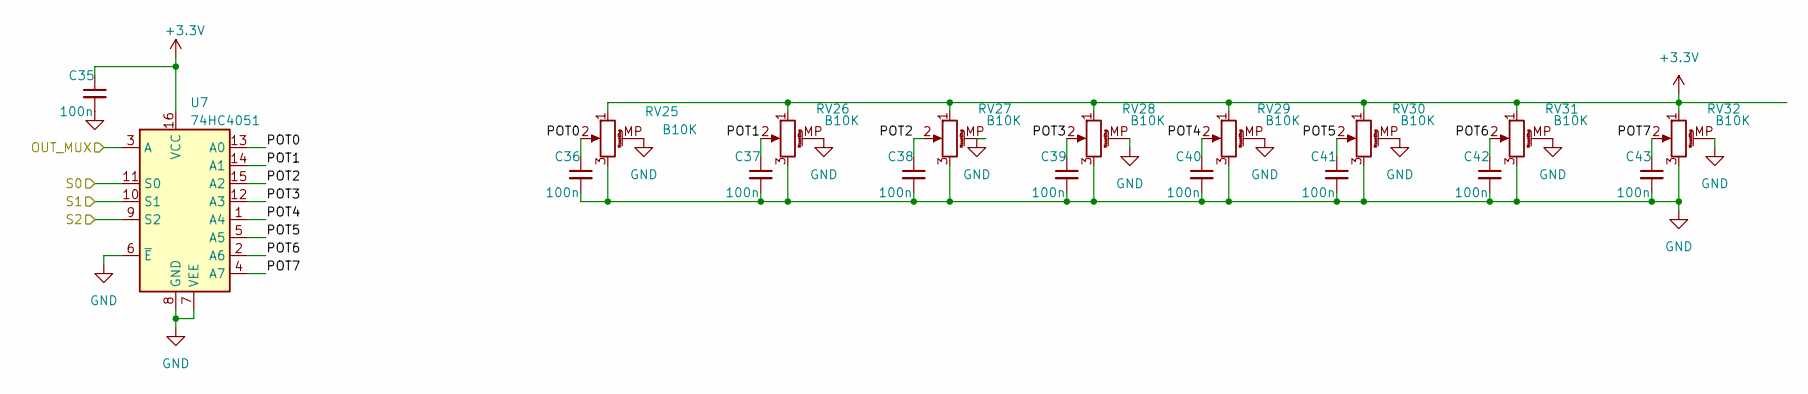
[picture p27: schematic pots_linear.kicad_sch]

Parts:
C35, C36, C37, C38, C39, C40, C41, C42, C43: 100n; C_0603_1608Metric
RV25, RV26, RV27, RV28, RV29, RV30, RV31, RV32: B10K; Potentiometer_Bourns_PTA3043_Single_Slide
U7: 74HC4051; SO-16_3.9x9.9mm_P1.27mm

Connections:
+3.3V: C35.1, RV25.1, RV26.1, RV27.1, RV28.1, RV29.1, RV30.1, RV31.1, RV32.1, U7.16 (VCC); also elsewhere on the board
/potentiometer linear/POT0: C36.1, RV25.2, U7.13 (A0)
/potentiometer linear/POT1: C37.1, RV26.2, U7.14 (A1)
/potentiometer linear/POT2: C38.1, RV27.2, U7.15 (A2)
/potentiometer linear/POT3: C39.1, RV28.2, U7.12 (A3)
/potentiometer linear/POT4: C40.1, RV29.2, U7.1 (A4)
/potentiometer linear/POT5: C41.1, RV30.2, U7.5 (A5)
/potentiometer linear/POT6: C42.1, RV31.2, U7.2 (A6)
/potentiometer linear/POT7: C43.1, RV32.2, U7.4 (A7)
/sel0: U7.11 (S0); also elsewhere on the board
/sel1: U7.10 (S1); also elsewhere on the board
/sel2: U7.9 (S2); also elsewhere on the board
/voie3: U7.3 (A); also elsewhere on the board
GND: C35.2, C36.2, C37.2, C38.2, C39.2, C40.2, C41.2, C42.2, C43.2, RV25.3, RV25.MP (MountPin), RV26.3, RV26.MP (MountPin), RV27.3, RV27.MP (MountPin), RV28.3, RV28.MP (MountPin), RV29.3, RV29.MP (MountPin), RV30.3, RV30.MP (MountPin), RV31.3, RV31.MP (MountPin), RV32.3, RV32.MP (MountPin), U7.6 (~E), U7.7 (VEE), U7.8 (GND); also elsewhere on the board

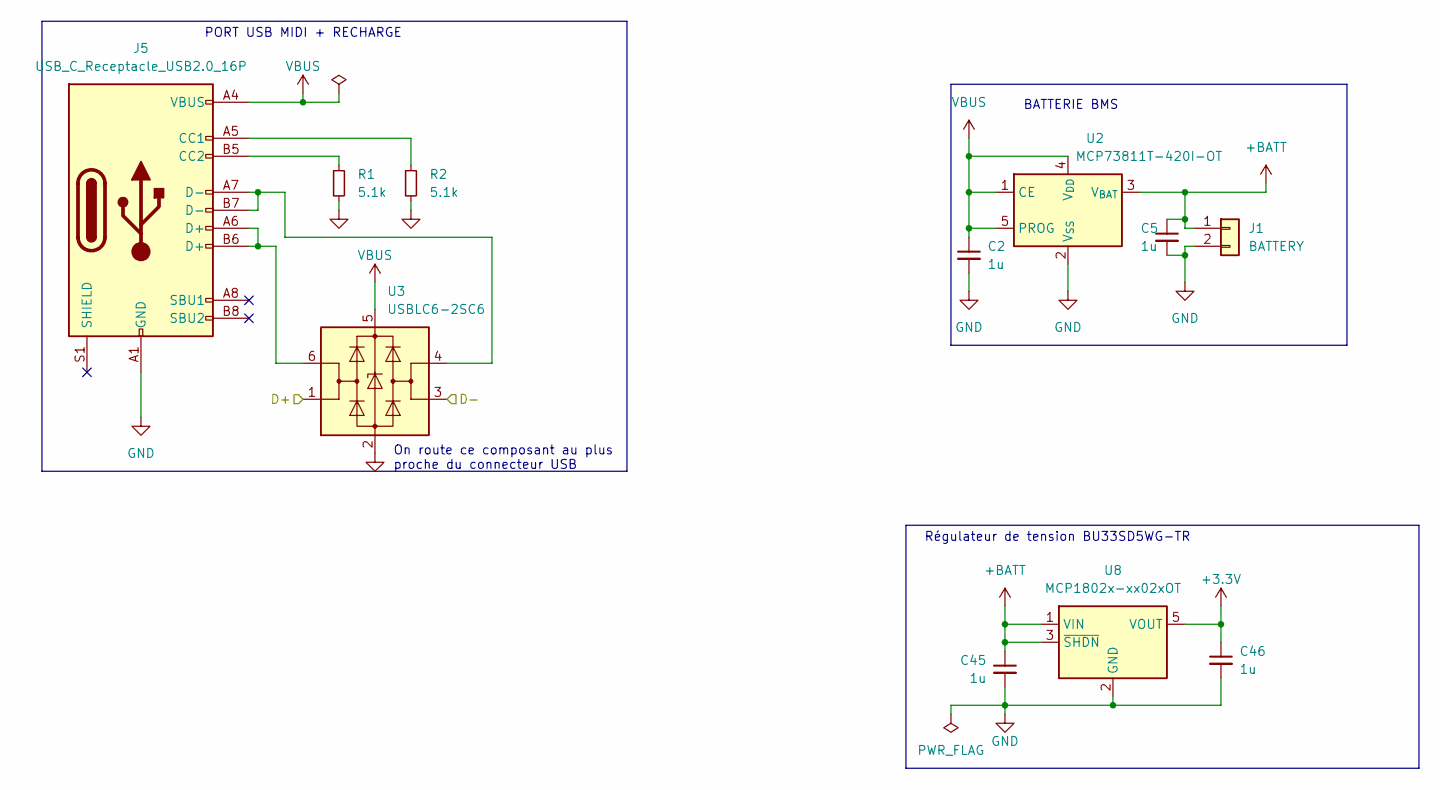
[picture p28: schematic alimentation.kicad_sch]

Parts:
C2, C5: 1u; C_0603_1608Metric
C45, C46: 1u; C_0603_1608Metric_Pad1.08x0.95mm_HandSolder
J1: BATTERY; JST_XH_S2B-XH-A_1x02_P2.50mm_Horizontal
J5: USB_C_Receptacle_USB2.0_16P; USB_C_Receptacle_GCT_USB4105-xx-A_16P_TopMnt_Horizontal
R1, R2: 5.1k; R_0603_1608Metric
U2: MCP73811T-420I-OT; SOT-23-5
U3: USBLC6-2SC6; SOT-23-6
U8: MCP1802x-xx02xOT; SOT-23-5

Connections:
+3.3V: C46.1, U8.5 (VOUT); also elsewhere on the board
+BATT: C5.1, C45.1, J1.1, U2.3 (V_{BAT}), U8.1 (VIN), U8.3 (~SHDN)
/D+: U3.1 (I/O1); also elsewhere on the board
/D-: U3.3 (I/O2); also elsewhere on the board
GND: C2.2, C5.2, C45.2, C46.2, J1.2, J5.A1 (GND), J5.A12 (GND), J5.B1 (GND), J5.B12 (GND), R1.2, R2.2, U2.2 (V_{SS}), U3.2 (GND), U8.2 (GND); also elsewhere on the board
unnamed: J5.A5 (CC1), R2.1
unnamed: J5.B5 (CC2), R1.1
unnamed: J5.A6 (D+), J5.B6 (D+), U3.6 (I/O1)
unnamed: J5.A7 (D-), J5.B7 (D-), U3.4 (I/O2)
VBUS: C2.1, J5.A4 (VBUS), J5.A9 (VBUS), J5.B4 (VBUS), J5.B9 (VBUS), U2.1 (CE), U2.4 (V_{DD}), U2.5 (PROG), U3.5 (VBUS)

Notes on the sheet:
Régulateur de tension BU33SD5WG-TR
On route ce composant au plus proche du connecteur USB
BATTERIE BMS
PORT USB MIDI + RECHARGE

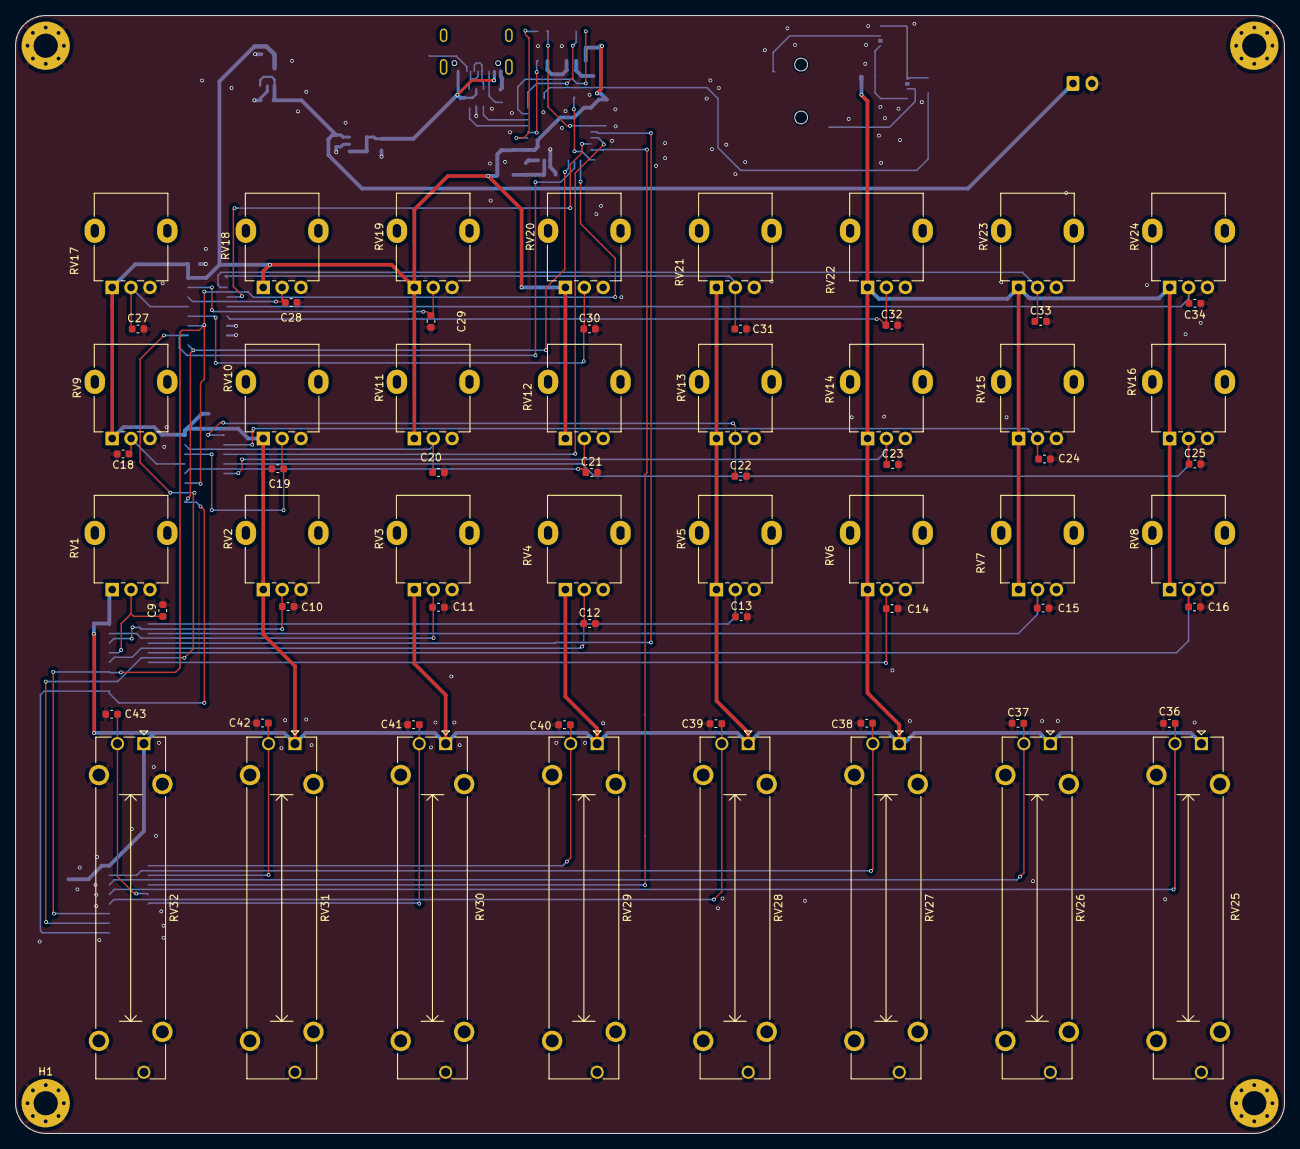
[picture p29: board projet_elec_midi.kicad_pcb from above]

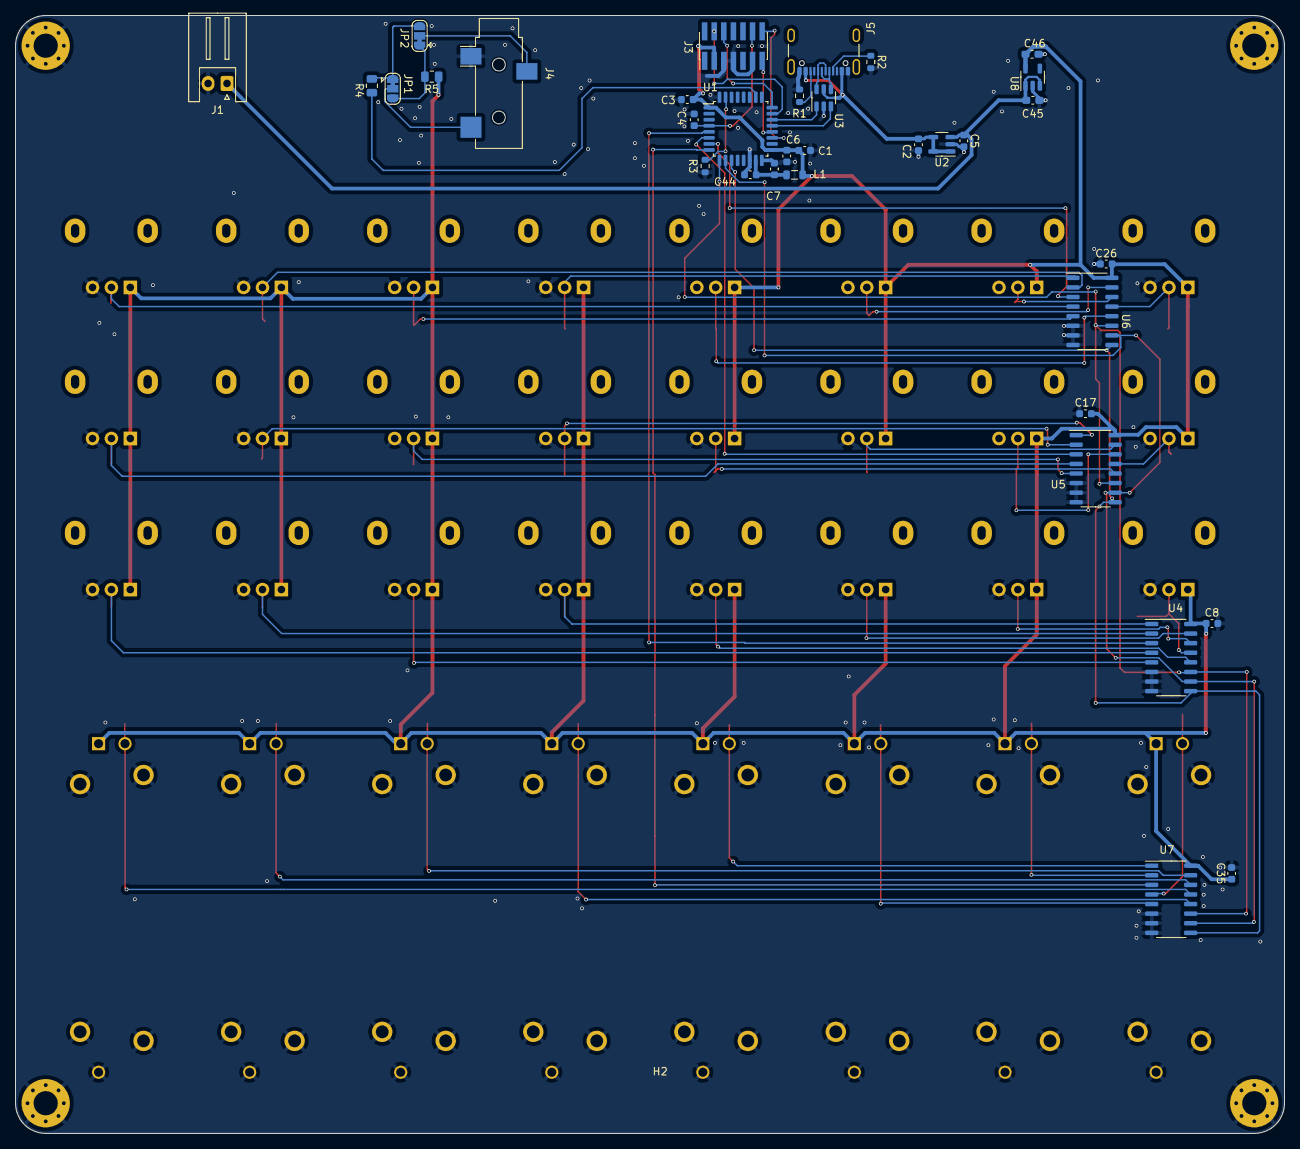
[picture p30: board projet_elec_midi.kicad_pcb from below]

Board: 2 copper layers, 168.0 x 148.0 mm, 102 parts (34 on the bottom side), 61 nets.

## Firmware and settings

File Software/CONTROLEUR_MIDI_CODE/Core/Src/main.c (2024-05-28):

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
/* Includes ------------------------------------------------------------------*/
#include "main.h"
#include "adc.h"
#include "dma.h"
#include "tim.h"
#include "usart.h"
#include "gpio.h"

/* USER CODE BEGIN Includes */
#include <stdio.h>
#include "MIDI_CONTROLLER.h"
#include "Analogue.h"
/* USER CODE END Includes */


void SystemClock_Config(void);
/* USER CODE BEGIN 0 */
// Pour lire les caractères du printf, sous linux :
// * Ouvrir un terminal
// * Taper la ligne suivante : minicom -D /dev/ttyACM0
// * Pour quitter : Ctrl+A puis Q

int __io_putchar(int chr)
{
	HAL_UART_Transmit(&huart1, (uint8_t*) &chr, 1, HAL_MAX_DELAY);

	return chr;
}

void HAL_ADC_ConvCpltCallback(ADC_HandleTypeDef *hadc)
{
	Analogue_irq_callback();
}
/* USER CODE END 0 */

/**
  * @brief  The application entry point.
  * @retval int
  */
int main(void)
{
  /* MCU Configuration--------------------------------------------------------*/

  /* Reset of all peripherals, Initializes the Flash interface and the Systick. */
  HAL_Init();

  /* Configure the system clock */
  SystemClock_Config();

  /* Initialize all configured peripherals */
  MX_GPIO_Init();
  MX_DMA_Init();
  MX_USART2_UART_Init();
  MX_ADC1_Init();
  MX_TIM6_Init();
  MX_USART1_UART_Init();
  /* USER CODE BEGIN 2 */

	printf("=====================================================================\r\n");
	Analogue_init();
	//uint16_t adc_tab[4];
	//HAL_ADC_Start_DMA(&hadc1, (uint32_t*)adc_tab, 4);
	//HAL_TIM_Base_Start(&htim6);

  /* USER CODE END 2 */

  /* Infinite loop */
  /* USER CODE BEGIN WHILE */
	while (1)
	{
		/*uint8_t data = 0x1A;
		HAL_HalfDuplex_EnableTransmitter(&huart1);
		HAL_UART_Transmit(&huart1,&data, 1, HAL_MAX_DELAY);
		HAL_Delay(1);*/
		Analogue_process();
/*
		HAL_GPIO_WritePin(LD2_GPIO_Port, LD2_Pin,0);
		HAL_Delay(10);
		HAL_GPIO_WritePin(LD2_GPIO_Port, LD2_Pin,1);
		HAL_Delay(10);*/
    /* USER CODE END WHILE */

    /* USER CODE BEGIN 3 */
	}
  /* USER CODE END 3 */
}

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


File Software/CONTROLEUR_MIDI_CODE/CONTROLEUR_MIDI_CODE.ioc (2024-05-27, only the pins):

Mcu.UserName=STM32G431KBTx
PA0.Signal=ADC1_IN1
PA1.Signal=ADC1_IN2
PA10.Signal=USART1_RX
PA13.GPIO_Label=T_SWDIO
PA13.Signal=SYS_JTMS-SWDIO
PA14.GPIO_Label=T_SWCLK
PA14.Signal=SYS_JTCK-SWCLK
PA2.GPIO_Label=USART2_TX [ST-LINKV3E_VCP_RX]
PA2.Signal=USART2_TX
PA3.GPIO_Label=USART2_RX [ST-LINKV3E_VCP_TX]
PA3.Signal=USART2_RX
PA4.Signal=GPIO_Output
PA5.Signal=GPIO_Output
PA6.Signal=GPIO_Output
PA9.Signal=USART1_TX
PB0.Signal=ADC1_IN15
PB3.GPIO_Label=T_SWO
PB3.Signal=SYS_JTDO-SWO
PB8-BOOT0.GPIO_Label=LD2 [green]
PB8-BOOT0.Signal=GPIO_Output
PF0-OSC_IN.Signal=ADC1_IN10

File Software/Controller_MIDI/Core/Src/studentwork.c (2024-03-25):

/*
 * studentwork.c
 *
 *  Created on: Mar 25, 2024
 *      Author: eleve
 */

#include "studentwork.h"
extern UART_HandleTypeDef huart2;

int values[32];

void setup() {
	// Activation des ADC
	HAL_ADC_Start(&hadc1); // pour stopper l'ADC: HAL_ADC_Stop(&hadc1);
	HAL_ADC_Start(&hadc2);
	HAL_ADC_Start(&hadc3);
	HAL_ADC_Start(&hadc4);
}

void loop() {
	uint32_t ADCValue;
	for (int sel = 0; sel < 8; sel++) { // Check change of each potentiometers
		on_off_pins_sel(sel); // Sélectionne 4 potentiomètres
		// Check MUX 0
		if (HAL_ADC_PollForConversion(&hadc1, 1000000) == HAL_OK) { // Wait that MUX change their output
			ADCValue = HAL_ADC_GetValue(&hadc1); // Take ADC result
			if (ADCValue != values[sel]) {
				values[sel] = ADCValue; // Save new value
				send_new_position(sel, ADCValue); // Send new value
			}
		}
		// idem avec les autres mux
	}
	HAL_Delay(1000);
}

void on_off_pins_sel(sel) {
	// Put sels
	HAL_GPIO_WritePin(GPIOA, GPIO_PIN_4, GPIO_PIN_RESET);
	//...
}

void send_new_position(ligne, colone) {
	// Send the new value by MIDI liaison
	//HAL_UART_Transmit_IT(&huart2,(uint8_t*)str,strlen(str));
}

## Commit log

2024-02-26 Update README.md
    Ajout des noms des élèves
2024-03-04 liste produit
    [produits.ods]
2024-03-04 Explication de comment créer un clone git
2024-03-04 Ajout de la batterie a achetter
    [produits.ods]
2024-03-11 Potentiomètres
    [produits.ods]
2024-03-11 slides-seance 1
    [produits.ods]
2024-03-11 Produits a achetter
    [produits.ods]
2024-03-18 Kicad schematic terminée
    [alimentation.kicad_sch, pots_circular.kicad_sch, pots_linear.kicad_sch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]
2024-03-18 Kicad début du routage
    [projet_elec_midi.kicad_pcb]
2024-03-25 software STM32
2024-03-25 Routage en double face
    [alimentation.kicad_sch, pots_circular.kicad_sch, pots_linear.kicad_sch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]
2024-04-22 Kicad version 8 - PCB presque finit
    [alimentation.kicad_sch, pots_circular.kicad_sch, pots_linear.kicad_sch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]
2024-04-29 Code de l'ADC avec un DAN
2024-05-04 Routage de la carte fini
    [projet_elec_midi.kicad_pcb]
2024-05-13 ADC fini test MIDI UART
2024-05-27 Tous les composants
    [Composants.ods]
2024-05-28 valeurs des pots
2024-06-03 Update README.md
    valeurs des potentiomètres
2024-06-04 Update README.md
    Analyse des trames MIDI
2024-06-04 Update README.md
    vitesse de transmission
2024-06-04 Add files via upload
    planning et cahier des charges
2024-06-04 Update README.md
    Ajout du cahier des charges et du planning
2024-06-04 Add files via upload
    Image du PCB final
2024-06-04 Update README.md
    image PCB
2024-06-04 Update README.md
    ajout des difficultés

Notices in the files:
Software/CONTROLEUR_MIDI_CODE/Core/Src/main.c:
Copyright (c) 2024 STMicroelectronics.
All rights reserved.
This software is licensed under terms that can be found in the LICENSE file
